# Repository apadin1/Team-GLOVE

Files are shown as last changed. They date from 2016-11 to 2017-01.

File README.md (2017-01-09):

# Team-GLOVE
## EECS 473 Final Project

This project was created as part of a Major Design Experience (MDE) by five senior Computer Engineering students at the University of Michigan. The goal of the project was to create a pair of gloves that could behave as controllers for any PC video game using the standard HID protocol. The gloves collected data from flex sensors in the fingers, capacitive touch sensors in the fingertips, and an IMU mounted on the back of the hand, and transmitted this data wirelessly over bluetooth to a receiver board which translated the data into stardard keyboard and mouse commands. To read more about the results of this project, you can see our [final report](Team%20GLOVE%20Final%20Report.pdf) and [project poster](Team%20GLOVE%20Poster.pptx.pdf) which are included in this repository.

We have decided to make this repository public in the hopes that others could expand upon our work. Our goal is to make video games more fun, intuitive, and immersive, and we hope that you can help.

Sincerely,

Team GLOVE

Nick Bertoldi, Ben Heckathorn, Ryan O'Keefe, Adrian Padin, Tim Schumacher

## Repository Organization
This repository is divided into several sections:
* ConfigApp - Contains code for a Windows app which was used to configure the inputs on the glove. It is mostly written in C#
* Hardware - This folder holdsthe eagle and gerber files for the PCB that was designed to run on the glove
* mbed-dongle-firmware - The code that ran on the reciever board (USB dongle) that did the translation and generated keyboard and mouse commands
* mbed-glove-firmware - The software running on the glove itself to collect sensor data and transmit to the receiver

## Compiling mbed-cli
This project was created using the mbed real-time operating system and libraries. It was specifically designed to run on the NRF51822 processor because of the built-in Bluetooth capabilities. 

To get started with the mbed environment, you can check out their website: www.developer.mbed.org

For instructions on how to setup the mbed-cli, see their documentation page: https://docs.mbed.com/docs/mbed-os-handbook/en/5.1/dev_tools/cli/

You will also need GCC ARM embedded compiler, version 4.9, which can be found here: https://launchpad.net/gcc-arm-embedded/4.9/4.9-2015-q3-update

For Linux users, we recommend installing to /usr/local/ (just `tar -xjvf` the download in that dir)

You will also need git, python, and several python dependencies, as described in the mbed-cli instructions

To setup the enviroment in our repo, go into the mbed-glove-firmware folder and type `mbed-deploy` to update the mbed-os lib

## Contributing
This software is licensed under the Apache 2.0 software license. If you would like to contribute, please submit a pull request and we can review your changes before we apply them. If you would like to use this project as a starting point for other projects, consider forking this repository using the Fork button above. Just be sure to cite this repository in your work!

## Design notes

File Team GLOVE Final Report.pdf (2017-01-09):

# Team GLOVE ‑ Wireless Gaming Gloves

EECS 473
Fall 2016

Team members: Nick Bertoldi, Ben Heckathorn, Ryan O’Keefe, Adrian Padin, Tim Schumacher

## Introduction

Over the course of the last decade, video game makers have sought to create a more immersive experience through high definion graphics, virtual reality, and augmented reality. However, there are currently only two opons for controlling these games: a standard controller, or a keyboard and mouse. The divide between immersive gameplay and a tradional, buᙀon‐based control scheme has created huge demand for a controller soluon that provides a more realisc gaming experience. The focus of our project was to develop a glove‐based controller, which would allow a user’s hand and finger gestures to be translated into control inputs for a
computer game. We were able to accomplish this through the use of touch, moon, and flex sensors to allow for a wide variety of different input methods. These inputs could be used both in exisng games, and as new opons for game developers in the future.

The result of this project was a pair of wireless gloves that handle communicaon via Bluetooth Low Energy (BLE). The gloves could then send input to a Windows computer, and behave like a wireless keyboard and mouse. Each glove contains various sensors used to capture different gestures, which are then translated into PC input. The glove inputs can be adjusted through a configuraon app to allow customizaon of controls for specific games. The final product meets all of the fundamental goals of the original proposal with the excepon of the heart rate sensor, which was removed early in the development cycle due to constraints in engineering me. During the COE Design Expo, several games, including Portal 2 and Fallout 4, were demonstrated successfully via glove control.

## Project Description

The focus of the project was to create a more intuive, immersive, and unique way to interact with exisng computer games. Currently, the main control opons for computer games are either a keyboard and mouse combo, or a USB controller. These input methods rely on the use of several buᙀons, and do not track hand moon or gestures. Therefore, these outdated control methods interrupt the feeling of immersion that computer games aim to provide. There is currently a gap in the market for a controller that feels more natural and does not require the user to hold something and press buᙀons. This means there is currently a demand for a controller that feels more like an extension of our natural movement. Products like the Nintendo Wii and HTC Vive have aᙀempted to fill this gap to some degree, but they sll face technical shortcomings including: inaccurate hand and wrist moon, or reliance on input via buᙀon presses. Ideally, a user should be able to perform acons in the real world, and have them translate directly to on‐screen acons with a high degree of precision. Currently, precision performance capture gloves, designed to track hand posion and gesture, exist, but they are not built for gaming. The integraon of this advanced technology into gaming may be years away, so we chose to develop a glove‐based controller that worked with exisng games in an aᙀempt to bridge the gap between current and future technology.

## High‐Level Descripon

Our group decided to create a pair of gloves that could operate in place of a keyboard and mouse to control exisng computer games. The gloves allow a user to have their hand and finger gestures translated into standard keyboard and mouse inputs. This is accomplished through the use of touch, moon, and flex sensors allowing for a wide variety of gaming inputs for use in both exisng games, and as new opons for future game developers. For example, a user can squeeze their finger and the computer could interpret this as “spacebar”, which could then be interpreted as a jump command. A major benefit of this method is that the gloves can mimic any keyboard or mouse input. Therefore, they can be used with any game, and an easy mapping from hand gestures to in‐game acons can be provided.

It is important to note that the glove is not meant to be a “virtual‐reality” glove. It does not track absolute three‐dimensional hand or finger posion, and it does not provide any hapc or vibraon feedback, which was one of the inial stretch goals. Rather, the focus of this project is to provide a different way to play exisng PC games now, and to build an interface that could easily be integrated into future games. This would allow future games to take advantage of the unique inputs that the gloves provide, and make beᙀer use of the data provided.

## System Layout

The layout of the system is two gloves, one for the le hand and one for the right hand, and a receiver board connected to the computer via USB. Each glove connuously collects data from sensors and then broadcast that sensor data over Bluetooth Low Energy (BLE) to the receiver, which analyzes the data and maps it to standard keyboard and mouse input. This input is sent to the computer using the Human Interface Device (HID) protocol (see Figure 1 below). The sensors on the glove are flex sensors that measure the deflecon of each of the four fingers, capacive touch sensors that funcon like buᙀons when the thumb is pressed to the pad of a finger, and an IMU for moon‐sensing to determine the absolute pitch, roll, and yaw of each hand (layout in Figure 2).

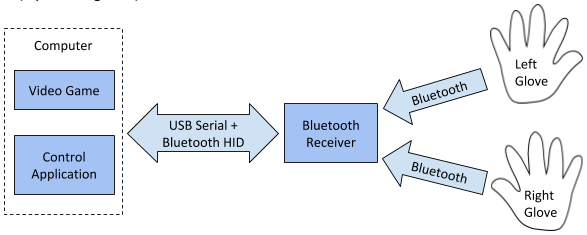
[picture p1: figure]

Figure 1: High‐level diagram of user interacon with the gloves. Gloves collect sensor data from the user and send it via Bluetooth to the receiver.

## Sensors

The gloves use a combinaon of flex sensors, a capacive sensor, and an IMU to capture gestures form the user (Figure 2). The flex sensors are made of a thin, flexible material that has a variable resistance, and measure 2.2” long. The sensor’s resistance changes from 30kΩ when straight to 90kΩ when fully bent. By placing the sensors along the middle knuckle of each finger, the bend of the finger is precisely measured. Along with the flex sensors, the AT42QT1070 capacive touch chip sits on the PCB and connects to the touch sensor pads via wires in the fabric. The touch sensor chip measures the capacitance of the pads, and registers when the value changes. The final on the PCB is the BNO055 IMU. This parcular chip combines a standard IMU with a ARM Cortex M0 to provide euclidian posion informaon to the processor at a rate of 100 Hz.

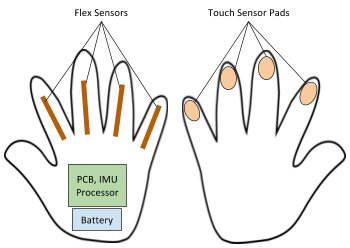
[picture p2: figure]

Figure 2: Layout of sensors in the final glove design. Back of the hand (le) and palm of the hand (right).

## Glove Construcon

The final glove assembly needed to be lightweight, comfortable, self‐contained, and reasonably professional‐looking (see Figure 3). This was important in order to differenate the project from previous glove‐based projects in the class that were fairly haphazard in their construcon, since a poorly‐constructed prototype not only appears unfinished and unprofessional, but can develop funconal issues with loose or poorly connected wires. Our design strategy, therefore, was to start with a preconstructed base glove, aᙀach sensors to it, cover the sensors to protect them, and then only expose the touch pads and status lights. The electronic components would be hidden

The components that make up the final construcon on each base glove include a PCB, four flex sensors, four touch sensor pads, a rechargeable baᙀery, a pair of indicator lights, and wiring to connect it all together. The base gloves are a pair of men’s large, black cycling gloves, with microsuede palms and synthec materials on the fingers. These gloves provide enough space for components to be securely aᙀached, and are easy to sew addional covering onto for the components. The PCB aᙀaches to to the glove at the back of the palm with adhesive velcro to hold it in place while allowing it to be taken out as needed during development. Each flex
sensor is anchored on the first segment of the finger below the knuckle, with the rest of their length inside a spandex sleeve sewn to the finger. Anchoring at the base end relieves stress from the delicate leads, while allowing the sensor to freely bend along with the finger. On the pad of each finger, copper foil is aᙀached to a wire, that then plugs into headers on the PCB. The
copper foil is adhesive and scks to the glove reasonably well, and is then covered around the edges with sewn leather to give it a more finished look and extend the durability of the copper pads. Just above the wrist, the baᙀery sits inside a band of elasc that is sewn into the glove and plugs into the header on the PCB. Finally, a large piece of leather covers the back of the glove and is secured with two sewn in snaps on the side to allow access to the internal components. Access is also required to get to the on/off switch and the micro‐USB header to charge the baᙀery. Built into the cover is the strip of two indicator lights, placed prominently on the gloves to relay status informaon to the user.

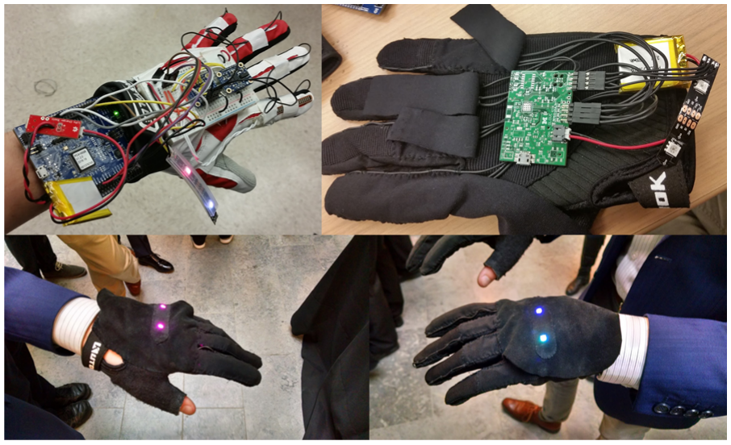
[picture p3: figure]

Figure 3: Prototype glove (top le), parally assembled final glove showing PCB, baᙀery, lights and wiring (top right), fully assembled and working gloves (boᙀom).

## PCB Design

A printed circuit board (PCB) was used to secure and arrange the processor, sensor chips, and Bluetooth antenna. This board allowed the final gloves to have a more rigid and compact structure than our prototype. The pcb had no explicit size requirement, aside from the need to fit on the back of an average adult hand; however, the final result is comparavely dense with an area close to 3 in ²

. Both gloves share an idencal PCB (shown in Figure 4).

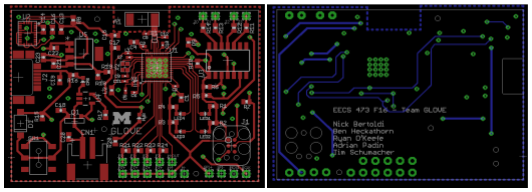
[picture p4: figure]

Figure 4: Eagle files screenshots of the PCB design, top (le) and boᙀom (right).

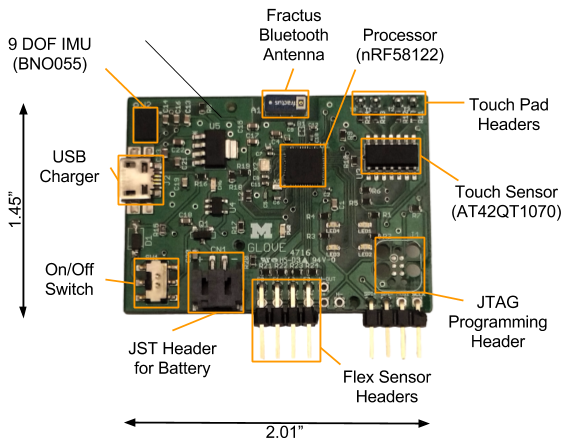
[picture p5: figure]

Figure 5: Layout of the major components on the PCB, including the processor and sensors

## Configuraon App

The mapping of sensor data to keyboard and mouse input can be adjusted through the Glove Configuraon App (Figure 6). The Windows applicaon allows the user to change the input associated with each sensor. Any of the fourteen inputs on each hand can be mapped to any standard keyboard key, or mouse input, which includes of cursor movement and buᙀon clicks. This allows the user to play a variety of games with the gloves, as well as le靀ng the user customize their gaming experience based on which acons seem more natural.

Due to the adjustable inputs, a user is not required to use both hands at mes, or be restrained to using certain fingers for specific acons. Currently, this is a major limitaon in games that use a keyboard and mouse because mice are not usually designed to be le‐handed, and keyboards can have fixed se靀ngs.

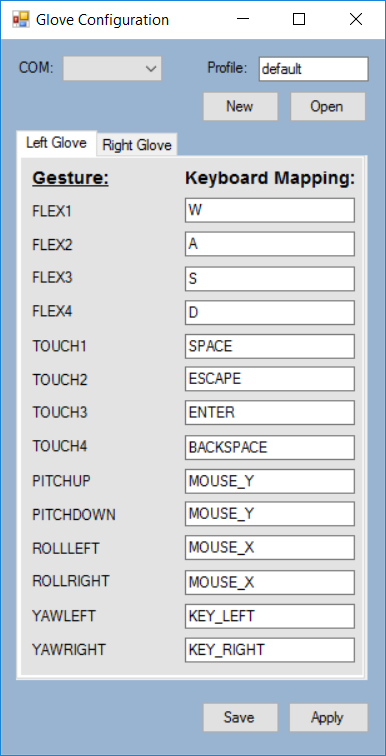
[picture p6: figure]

Figure 6: The configuraon app

## Schedule, Milestones, and Budget

Due to soware and hardware delays, the project was consistently behind schedule by roughly two weeks when compared to the proposed schedule. The details of a few important me and budget setbacks are detailed later in this report. To offset the hardware producon issues, we decided to focus on soware earlier on to minimize tesng once we received our PCBs.

The original milestone deliverables consisted of the following items:

Milestone 1
- Flex and touch sensors working, reading data properly
- Bluetooth communication scheme implemented and completed
- Receiver able to get commands from computer over USB
- Receiver able to send data through a HID profile
- Able to collect IMU data and interpret it somehow
- Starng work on desktop configuraon app

Milestone 2
- PCBs designed and ordered
- Prototype completed, usable with at least one game
- IMU, flex, touch, heart rate sensors all reading data correctly
- Desktop app almost finished, usable with prototype
- Several HID profiles implemented, configurable through desktop app

Overall, the order in which these tasks were completed did not change. Nearly every task started about a week later than planned, and finished about two weeks later than previously ancipated. The original schedule had allowed for two weeks of tesng and playing with the final product, so, as a result, that tesng me had to be reduced to three days. However, all of the original milestone projecons and features were incorporated into the final product.

The budget stayed similar to the proposed budget. Certain features had to be cut out early on, such as the hapc feedback, which was one of the original stretch goals. As a result, the buzzer motors were not purchased and fewer flex sensors were bought. There were also a series of unforeseen expenses. The biggest change to the budget was due to the delay in the original PCB order. The boards were designed and ordered the weekend before the given deadline on November 8th, but due to shipping issues they did not arrive unl November 30th, which was a full week aer the vendor’s adversed worst case delivery me. Once it was clear that the shipment would be delayed, the group made the decision to do a second order from a more reputable site, but it sll cost extra for expedited shipping to meet the deadline. Also, several mistakes were made when soldering the boards that meant that various other components also needed to be reordered. However, the budget had a conngency for this parcular problem and it did not cause any major issues.

## Lessons Learned

There were many mistakes that were made and many lessons that were learned the hard way in this project. The first issues arose with our original PCB design. Since no one in the group had the knowledge nor inclinaon to make our own component footprints, we at first limited ourselves to only using components for which we could find an exisng footprint to use in Eagle, an easy to use PCB design program. We quickly realized that this was not sufficient since some of our crical components such as the moon and touch sensors did not already have footprints. We also realized aer we ordered our boards that we should have added several useful debugging features such as a so reset buᙀon, and USB data lines to read debugging informaon off of our processor. In addion, we should not have ordered our boards from a website which were not experienced with, as it caused delays of nearly a week and a half and ended up being lower quality than the boards we ordered later.

One very difficult issue was the use of HID for our keyboard and mouse input. At first we thought this would be easy because it seemed to be a cross‐plaᔀorm soluon with good documentaon. However, there ended up being very few hardware devices which supported true USB/HID, and integrang those devices seemed like an immense challenge. One of our group members discovered that we could implement HID over Bluetooth Low Energy and it seemed to work well at first. However, stability issues and connecon drops ended up plaguing the project throughout its development. For example, if the device tried to send commands at too fast of a rate, the Bluetooth stack would get overloaded aer a few minutes of playing a game and stop sending commands. Another major issue we encountered was when integrang a second glove aer ge靀ng the first glove working; the two gloves would oen overwrite each other's commands and inaccurate data would be sent. These issues were compounded by the use of the ARM mbed toolchain which was used to write our soware, which turned out to have bugs and did not support all of the features that it adversed. In the long run, it probably would have been beᙀer to use a board such as the PJRC Teensy, which implements USB funconality rather than use HID over BLE.

Despite these issues and several more, our team learned a lot about embedded systems design. A big part of this learning process was having to start our project from scratch, picking a processor and designing a PCB based on our requirements. We learned about how Bluetooth Low Energy communicaon works and how to balance tasks which require long amounts of me to run, such as scanning and sending data over Bluetooth. We also learned that prototyping is crical to determine exactly what is feasible and how best to implement ideas in order to catch mistakes early on.

## Contributions

Nick Bertoldi (20%) ‐ Nick contributed to the PCB design and tesng. He performed research into the communicaon scheme and wrote code and tests around HID over GATT communicaon and GAP adversements. He also designed and implemented the backend to the configuraon applicaon and designed serial communicaon code to interface with the receiver board.

Ben Heckathorn (20%) ‐ Ben contributed primarily to soware design and integraon. He also helped develop the high‐level communicaon scheme between the gloves, receiver, and CPU. He helped write the soware that translates glove data to HID input, and developed it to be completely configurable so that any sensor can map to any HID input. Ben also wrote porons of the receiver code by integrang various pieces of soware into the final version. In addion, Ben also designed the interface for the glove configuraon applicaon.

Ryan O’Keefe (20%) ‐ Ryan contributed to the PCB design layout. He also soldered together the PCBs when they came in. He fixed the touch sensor breakout board that we acquired for prototyping. He performed performance checking and debugging of the PCBs and fixed any soldering issues associated. Ryan also helped write the soware that translates the data coming from the sensors into a specific kind of input ‐ HID. He helped make the soware configurable so that any arbitrary sensor could be mapped to any arbitrary HID input.

Adrian Padin (20%) ‐ Adrian contributed primarily to the Bluetooth Low Energy and HID soware. He developed drivers for using BLE to send keyboard and mouse data and wrote the porons of the receiver code that scan for glove data and send HID data to the computer. Adrian also helped write a good poron of the Milestone and Final reports and created figures for the final report showing the high‐level diagram and glove layout.

Tim Schumacher (20%) ‐ Tim started by prototyping the flex, touch, and orientaon sensors by breadboarding them in the lab and wring the first drivers to collect sensor data. He connued to refine the sensor drivers and also developed the rest of the glove firmware that collects data from the sensors, sends BLE adversements with the sensor data, and controls the indicator lights on the glove. In addion to the glove firmware, he designed and built the prototype and final gloves, with much of the sewing assembly done in conjuncon with his mom, Marci Schumacher.

## Cost to Manufacture

We esmate that a reasonable quanty to manufacture this product as a consumer electronic device is 10,000 units. This number is based on the assumpon that this is an experimental device, but one that has a reasonably large pool of potenal buyers. In this instance, the potenal buyers are anyone who does PC gaming, and is reduced by the number of people who are willing to try the gloves and who can afford them.

The cost per board at this quanty would be approximately $22.50, which includes fabricang the boards, purchasing components, and assembling the boards. This does not include the cost of purchasing the materials for the glove and sewing them, but it otherwise gives a preᙀy reasonable expectaon of manufacturing costs, though perhaps a bit high if quanty discounts were considered.

## Final Parts List and Budget

The following two pages contain a spreadsheet of the complete part list of every component used to build this project and the total list of expenses. The part list covers all of the parts needed to make four boards, one set of complete gloves, and an extra glove as backup. The parts list is divided into the following secons:

Board components are all of the passive and acve components that had to be soldered to the board. This includes all of the passive components, such as resistors, capacitors, LEDs, oscillators, and transistors, and the acve components such as the touch sensors, IMU, and processor.

System components are parts that are needed to make any number of gloves, such as the leather and PCBs. Whereas the board components can be scaled down by a factor of four to make a single glove, these system parts are needed to make any number of boards.

Extra parts are parts that were used by the team in the development of this project but are not necessary to construct the final product. This includes items such as development kits, resistor kits, and spare components. Any parts which were used to make the prototype glove such as sensor breakout boards and programming materials are also included.

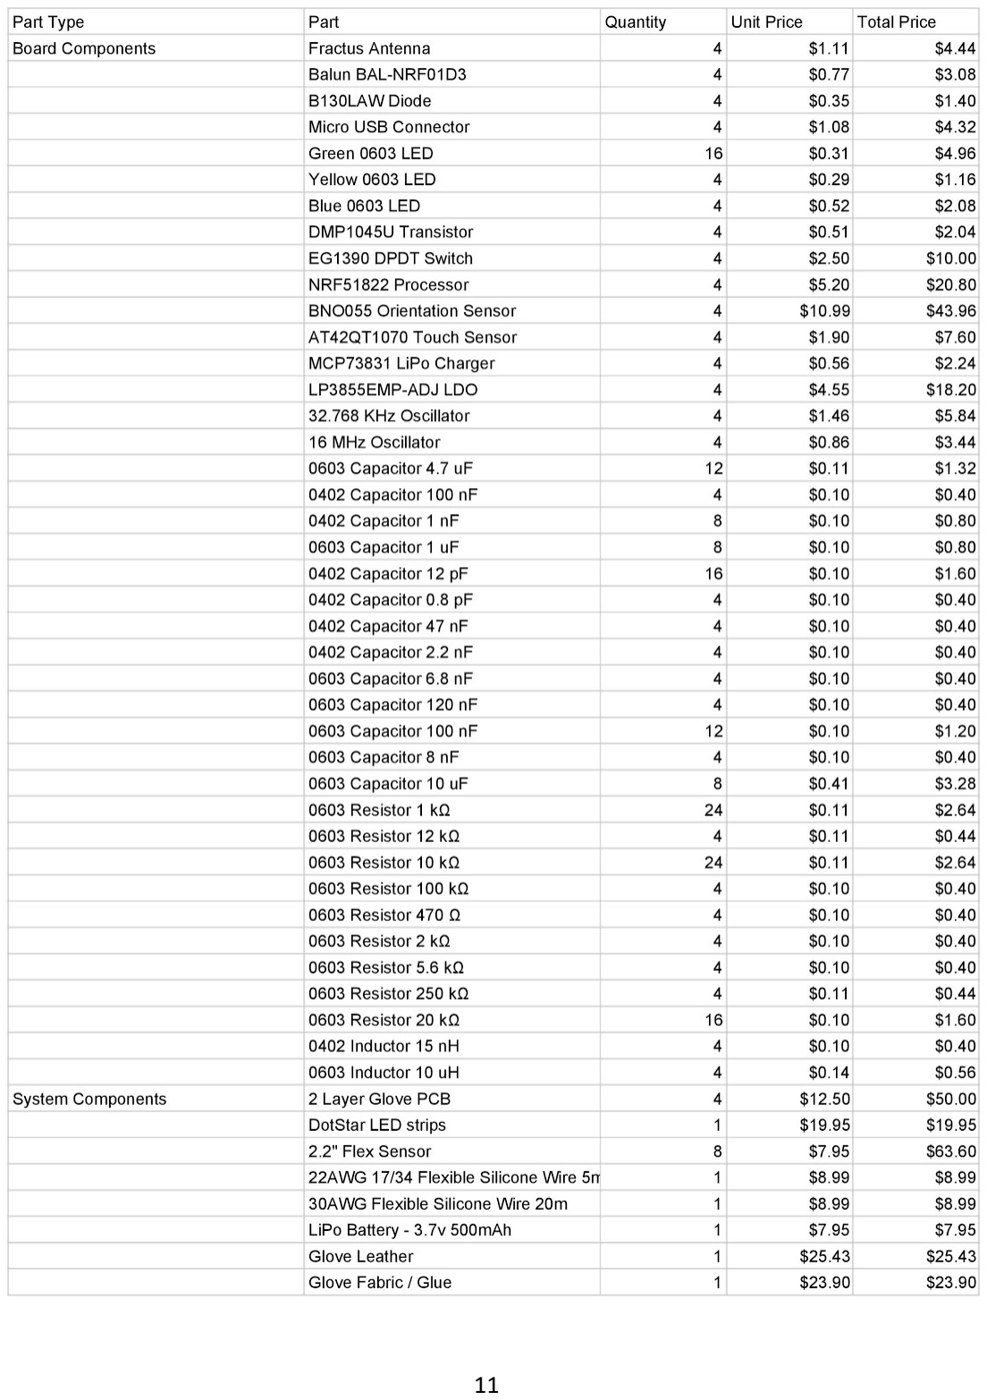
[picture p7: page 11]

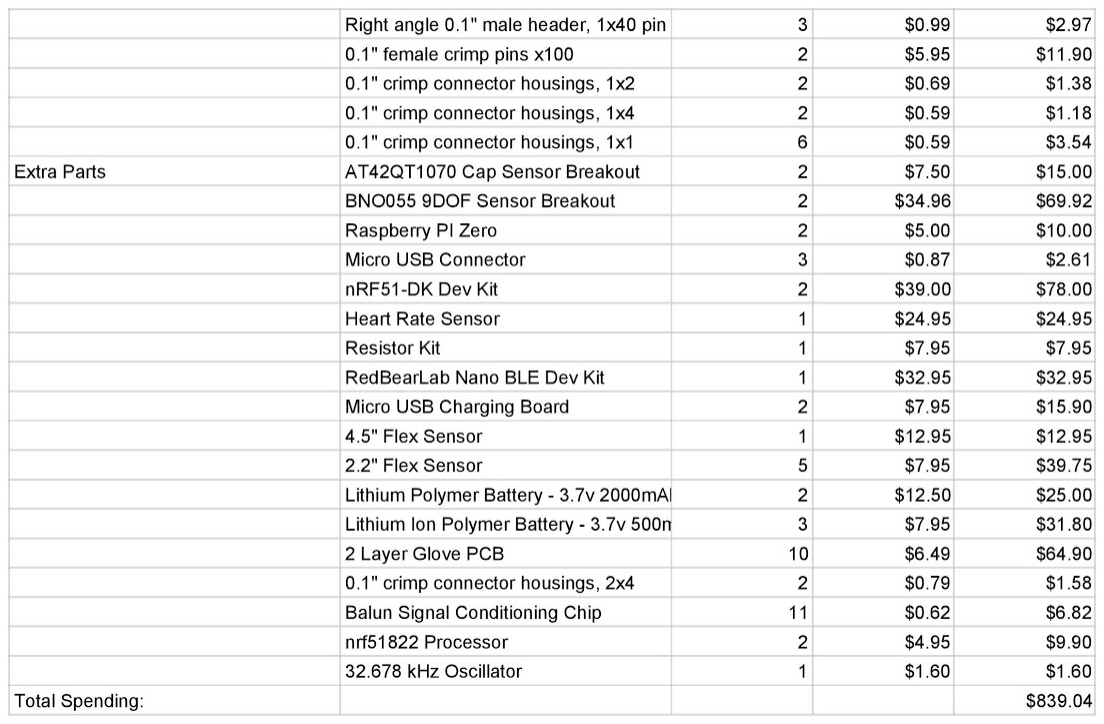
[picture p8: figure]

Note that the list does not cover shipping costs, which put the final expense value much closer to the maximum provided budget of $1,000. The final total cost was $999.91.

## References and Citations

All code was developed using the ARM mbed toolchain and compiled using the ARM‐GCC compiler. More informaon about ARM mbed can be found at there website here: hᙀps://developer.mbed.org/ .

Several hardware and soware design choices were based on similar designs from Lab 11. Credit goes to the Lab 11 crew for helping with these designs, especially the charging circuit and the Bluetooth antenna setup.

Special thanks goes to Branden Ghena, one of the Lab 11 staff who helped us a lot with both the final PCB design review, and bluetooth adversement debugging and opmizaon.

The 473 GSI Seth Goldstein helped us design parts of our PCB as well. He provided sample code from his EECS 473 project that helped us write the code to scan for bluetooth adversements and receive data from the computer over USB.

For more informaon about our project and to see our code for yourself, visit our Github repository: hᙀps://github.com/apadin1/Team‐GLOVE (https://github.com/apadin1/Team-GLOVE) .

## Appendix A: Completed PCB

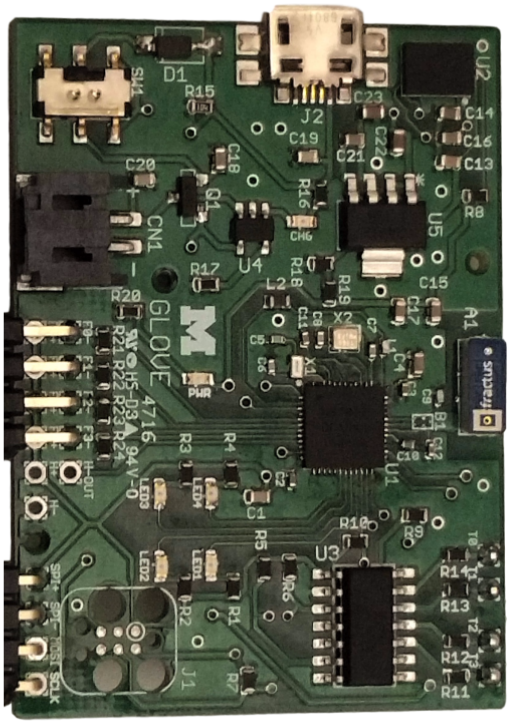
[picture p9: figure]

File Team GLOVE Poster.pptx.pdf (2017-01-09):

## Overview

The focus of the project is to create a more intuitive, immersive, and interesting way to interact with existing computer games. Traditional games are controlled using a keyboard and mouse, but gamers are eager for new ways to interact with the virtual world. Our solution was to create a glove-based controller that translated the user’s gestures into standard keyboard and mouse commands.

## Glove Sensors

A variety of sensors are incorporated into the gloves to give users different ways to interact with their games. Resistive flex sensors
(1) are placed along the knuckles detect when the user bends their fingers. A capacitive touch sensor (2) detects when the user touches their exposed thumb to the metal pads located on their fingertips. Lastly, an inertial measurement unit (3) detects when the user rotates their hand around an axis.

## PCB Design

Each glove has an identical printed circuit board (PCB) which connects the processor to its sensors. The sensors communicate to the processor over I²C and SPI protocols. The gloves can last up to 14 hours on a single charge. Status LEDs on the back of the hand communicate with the processor over SPI, and can indicate various programmable events. Once soldered, the circuit board is sewn into the glove to keep it secure.

## Using the Gloves

The setup consists of two gloves and a receiver board. Each glove continuously collects data from each finger’s flex sensor, capacitive touch sensor, and the IMU for motion-sensing. The gloves then broadcast the sensor data over Bluetooth to the receiver board, which is plugged into the USB port of the computer. The receiver analyzes the data and maps it to standard keyboard and mouse input to send to the computer.

## The HID Protocol

The Human Interface Device protocol (HID) is a standardized communication schemel used to send data to the computer from common input devices. This is what allows you to buy any keyboard off the shelf, plug it into your computer, and have it work instantly without need to install a new driver.

We chose HID for this project
because it allows the glove to
connect to any computer disguised as a keyboard and mouse, thus making it easy to use with existing computer games. Any game
that can be controlled with
a keyboard and/or mouse can be controlled with the gloves.

## Configuration App

## Prototyping

In order to test the software as it was being developed, a prototype glove needed to be created.The glove (5) incorporated each type of sensor used in the final glove, as well as a development kit to process the data and a mess of wires.

## Final Construction

The final gloves are built on top of a bike glove base layer. The thumb is exposed to allow for touch sensor input. The flex and capacitive sensors are attached to the fingers, and the PCB and battery are attached to the back of the hand. Suede covers the internals of the glove to create a functional and complete wearable device as demonstrated below (6).

# Wireless Interactive Glove-Based Controller for Computer Games

Nick Bertoldi, Ben Heckathorn, Ryan O’ Keefe, Adrian Padin, Tim Schumacher Fall 2016 – EECS 473: Advanced Embedded Systems

Special thanks to Professor Mark Brehob, Matt Smith, Branden Ghena, and Seth Goldstein for their support and assistance and thanks to Marci Schumacher for assistance in glove construction. Thanks as well to Boeing for providing funding for this project and for supporting EECS 473 and the College of Engineering at the University of Michigan.

Bluetooth

Bluetooth

Figure 5. Prototype glove featuring the nRF51-DK, DotStar LEDs, touch sensors, flex sensors, and IMU

Figure 1. Flex Sensor | Figure 2. Capacitive Touch Sensor
Figure 3. IMU

Figure 4. PCB Schematic (top) compared to the constructed PCB (bottom)

The Configuration App allows the user to change the command that each sensor controls. For instance, in the default settings shown right (8), bending the index finger of the left glove sends a “W” command to the computer, and rotating the left wrist moves the mouse cursor left and right. The ability to change the configuration allows the user to map
the inputs to fit their preferences. Figure 6. Final glove design with fabric pulled back to see the components and wiring

Figure 8. Interface for the configuration app

Figure 7. Communication scheme for Gloves

3.9mm

8.65mm
55.88mm

5.20mm

3.80mm

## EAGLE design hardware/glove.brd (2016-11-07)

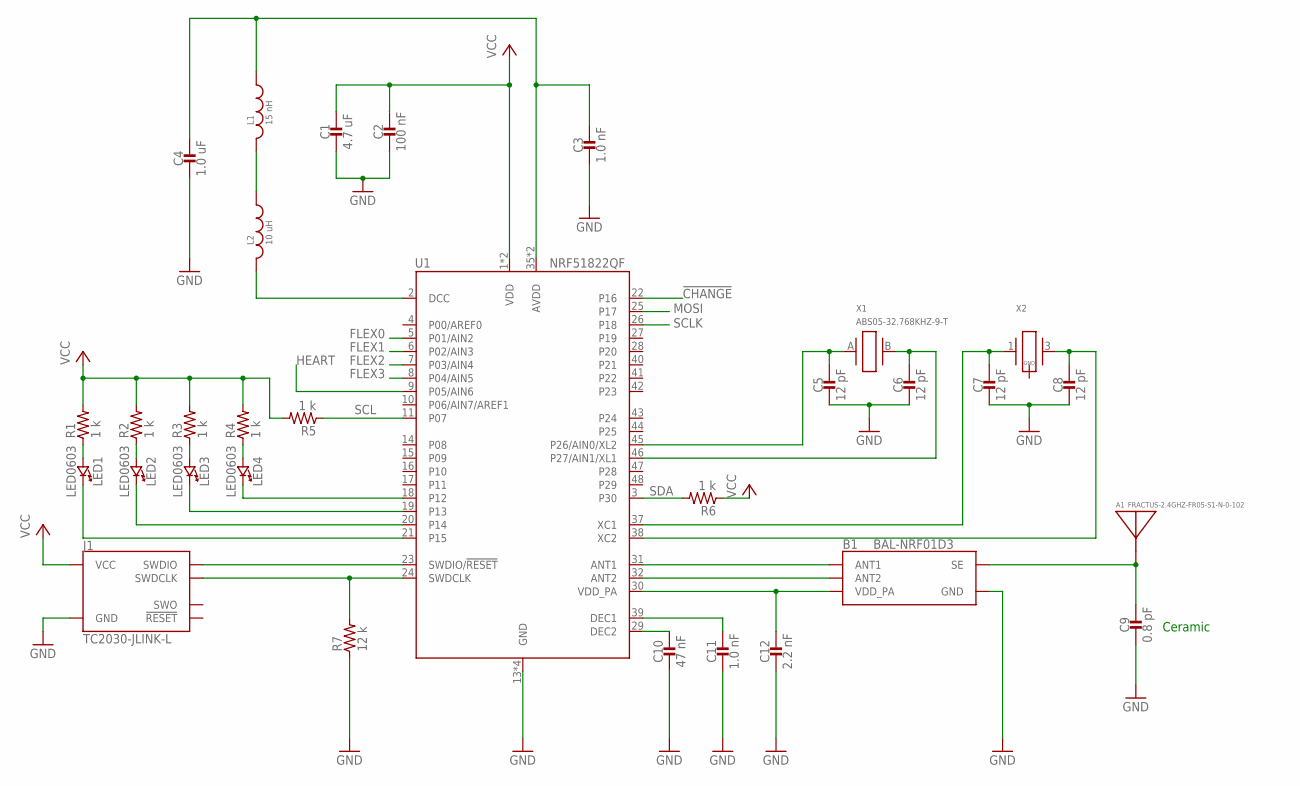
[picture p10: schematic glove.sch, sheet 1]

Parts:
A1: FRACTUS-2.4GHZ-FR05-S1-N-0-102; FRACTUS-ANTENNA-FR05-S1-N-0-102
B1: BAL-NRF01D3
C1: 4.7 uF; 0603_CAP
C2: 100 nF; 0402_CAP
C3, C11: 1.0 nF; 0402_CAP
C4: 1.0 uF; 0603_CAP
C5, C6, C7, C8: 12 pF; 0402_CAP
C9: 0.8 pF; 0402_CAP
C10: 47 nF; 0402_CAP
C12: 2.2 nF; 0402_CAP
J1: TC2030-JLINK-L; TC2030-IDC
L1: 15 nH; 0402_CAP
L2: 10 uH; 0603_CAP
LED1, LED2, LED3, LED4: LED0603; LED-0603
R1, R2, R3, R4, R5, R6: 1 k; 0603-RES
R7: 12 k; 0603-RES
U1: NRF51822QF; QFN-48-6MM
X1: ABS05-32.768KHZ-9-T; ABS05
X2: TXC-8Y

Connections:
!CHANGE: U1.22 (P16); also elsewhere on the board
FLEX0: U1.5 (P01/AIN2); also elsewhere on the board
FLEX1: U1.6 (P02/AIN3); also elsewhere on the board
FLEX2: U1.7 (P03/AIN4); also elsewhere on the board
FLEX3: U1.8 (P04/AIN5); also elsewhere on the board
GND: B1.GND, C1.2, C2.2, C3.2, C4.2, C5.2, C6.2, C7.2, C8.2, C9.2, C10.2, C11.2, C12.2, J1.5 (GND), R7.1, U1.13 (GND), U1.33 (GND), U1.34 (GND), U1.GND; also elsewhere on the board
HEART: U1.9 (P05/AIN6); also elsewhere on the board
MOSI: U1.25 (P17); also elsewhere on the board
unnamed: LED2.C (CATHODE), U1.20 (P14)
unnamed: LED2.A (ANODE), R2.1
unnamed: LED1.C (CATHODE), U1.21 (P15)
unnamed: LED1.A (ANODE), R1.1
unnamed: LED4.C (CATHODE), U1.18 (P12)
unnamed: LED4.A (ANODE), R4.1
unnamed: L2.2, U1.2 (DCC)
unnamed: L1.2, L2.1
unnamed: C3.1, C4.1, L1.1, U1.35 (AVDD), U1.36 (AVDD)
unnamed: J1.2 (SWDIO), U1.23 (SWDIO/!RESET)
unnamed: C8.1, U1.38 (XC2), X2.3 (2)
unnamed: B1.ANT1, U1.31 (ANT1)
unnamed: B1.ANT2, U1.32 (ANT2)
unnamed: B1.VCC (VDD_PA), C12.1, U1.30 (VDD_PA)
unnamed: A1.1, B1.SE, C9.1
unnamed: C10.1, U1.29 (DEC2)
unnamed: C11.1, U1.39 (DEC1)
unnamed: C5.1, U1.45 (P26/AIN0/XL2), X1.A (1)
unnamed: C6.1, U1.46 (P27/AIN1/XL1), X1.B (2)
unnamed: C7.1, U1.37 (XC1), X2.1
unnamed: J1.4 (SWDCLK), R7.2, U1.24 (SWDCLK)
unnamed: LED3.A (ANODE), R3.1
unnamed: LED3.C (CATHODE), U1.19 (P13)
SCL: R5.1, U1.11 (P07); also elsewhere on the board
SCLK: U1.26 (P18); also elsewhere on the board
SDA: R6.2, U1.3 (P30); also elsewhere on the board
VCC: C1.1, C2.1, J1.1 (VCC), R1.2, R2.2, R3.2, R4.2, R5.2, R6.1, U1.1 (VDD), U1.12 (VDD); also elsewhere on the board

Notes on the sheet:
Ceramic

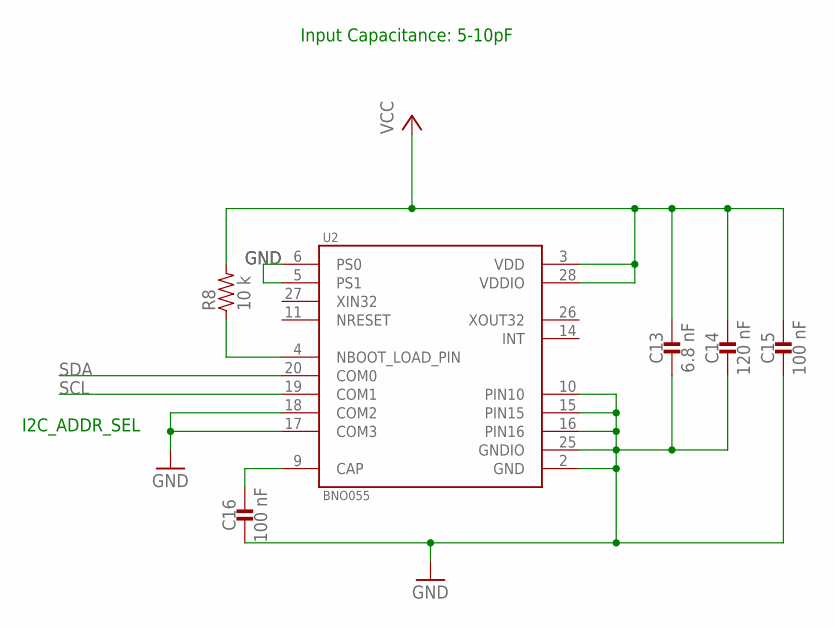
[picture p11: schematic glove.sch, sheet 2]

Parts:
C13: 6.8 nF; 0603_CAP
C14: 120 nF; 0603_CAP
C15, C16: 100 nF; 0603_CAP
R8: 10 k; 0603-RES
U2: BNO055; LGA28R50P4X10_380X520X100

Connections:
GND: C13.2, C14.2, C15.2, C16.2, U2.2 (GND), U2.5 (PS1), U2.6 (PS0), U2.10 (PIN10), U2.15 (PIN15), U2.16 (PIN16), U2.17 (COM3), U2.18 (COM2), U2.25 (GNDIO); also elsewhere on the board
unnamed: C16.1, U2.9 (CAP)
unnamed: R8.1, U2.4 (NBOOT_LOAD_PIN)
SCL: U2.19 (COM1); also elsewhere on the board
SDA: U2.20 (COM0); also elsewhere on the board
VCC: C13.1, C14.1, C15.1, R8.2, U2.3 (VDD), U2.28 (VDDIO); also elsewhere on the board

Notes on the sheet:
I2C_ADDR_SEL
Input Capacitance: 5-10pF

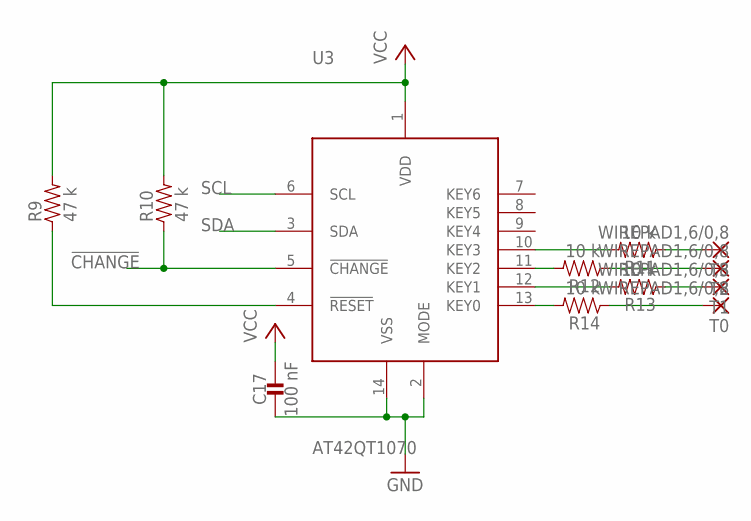
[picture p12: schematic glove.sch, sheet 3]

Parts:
C17: 100 nF; 0603_CAP
R9, R10: 47 k; 0603-RES
R11, R12, R13, R14: 10 k; 0603-RES
T0, T1, T2, T3: WIREPAD1,6/0,8; 1,6/0,8
U3: AT42QT1070; QT1070

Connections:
!CHANGE: R10.1, U3.5 (!CHANGE); also elsewhere on the board
GND: C17.2, U3.2 (MODE), U3.14 (VSS); also elsewhere on the board
unnamed: R11.2, U3.10 (KEY3)
unnamed: R11.1, T3.1
unnamed: R12.2, U3.11 (KEY2)
unnamed: R12.1, T2.1
unnamed: R13.2, U3.12 (KEY1)
unnamed: R13.1, T1.1
unnamed: R14.2, U3.13 (KEY0)
unnamed: R14.1, T0.1
unnamed: R9.1, U3.4 (!RESET)
SCL: U3.6 (SCL); also elsewhere on the board
SDA: U3.3 (SDA); also elsewhere on the board
VCC: C17.1, R9.2, R10.2, U3.1 (VDD); also elsewhere on the board

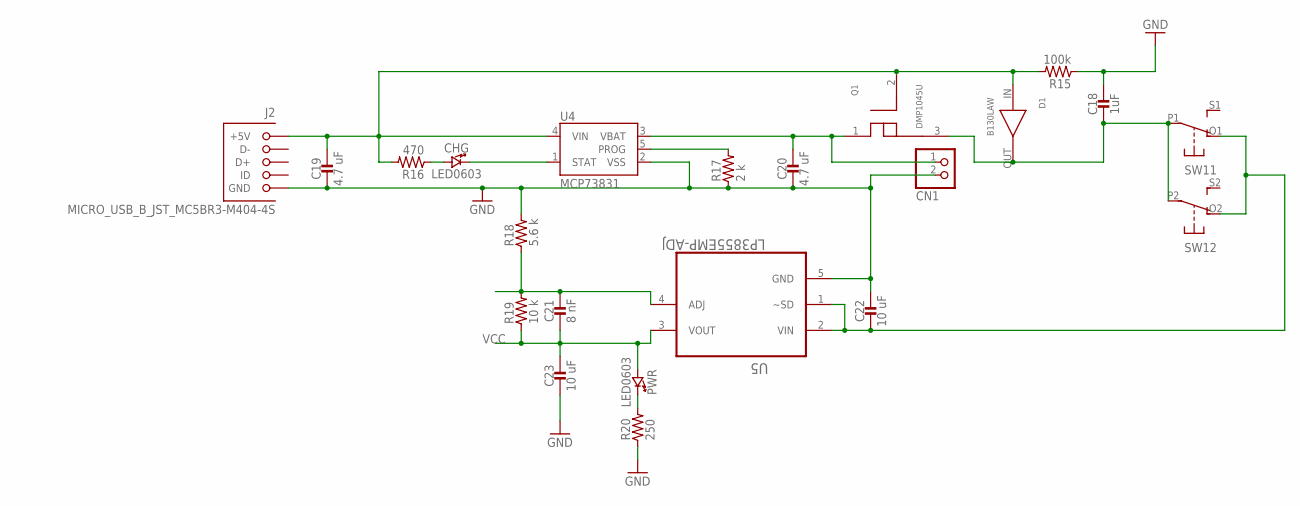
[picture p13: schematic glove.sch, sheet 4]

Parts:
C18: 1uF; 0603_CAP
C19, C20: 4.7 uF; 0603_CAP
C21: 8 nF; 0603_CAP
C22, C23: 10 uF; 0603_CAP
CHG: LED0603; LED-0603
CN1: JST_2PIN-SMT-RA; JST-PH-2-SMT-RA
D1: B130LAW; 2PIN
J2: MICRO_USB_B_JST_MC5BR3-M404-4S; USB_MICRO_B-JST-MC5BR3-M404-4S-TB
PWR: LED0603; LED-0603
Q1: DMP1045U; 3PIN
R15: 100k; 0603-RES
R16: 470; 0603-RES
R17: 2 k; 0603-RES
R18: 5.6 k; 0603-RES
R19: 10 k; 0603-RES
R20: 250; 0603-RES
SW1: DPDT-EG1390; EG1390
U4: MCP73831; SOT23-5
U5: LP3855EMP-ADJ; SOT150P696X180-5N

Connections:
GND: C18.1, C19.2, C20.2, C22.1, C23.2, CN1.2 (1), J2.5 (GND), R15.1, R17.1, R18.2, R20.1, U4.2 (VSS), U5.5 (GND); also elsewhere on the board
unnamed: C18.2, D1.OUT, Q1.3 (SOURCE), SW1.P1, SW1.P2
unnamed: CHG.A (ANODE), R16.1
unnamed: CHG.C (CATHODE), U4.1 (STAT)
unnamed: R17.2, U4.5 (PROG)
unnamed: C21.1, R18.1, R19.2, U5.4 (ADJ)
unnamed: PWR.C (CATHODE), R20.2
unnamed: C19.1, D1.IN, J2.1 (+5V), Q1.2 (GATE), R15.2, R16.2, U4.4 (VIN)
unnamed: C20.1, CN1.1 (2), Q1.1 (DRAIN), U4.3 (VBAT)
unnamed: C22.2, SW1.O1 (O), SW1.O2 (O), U5.1 (~SD), U5.2 (VIN)
VCC: C21.2, C23.1, PWR.A (ANODE), R19.1, U5.3 (VOUT); also elsewhere on the board

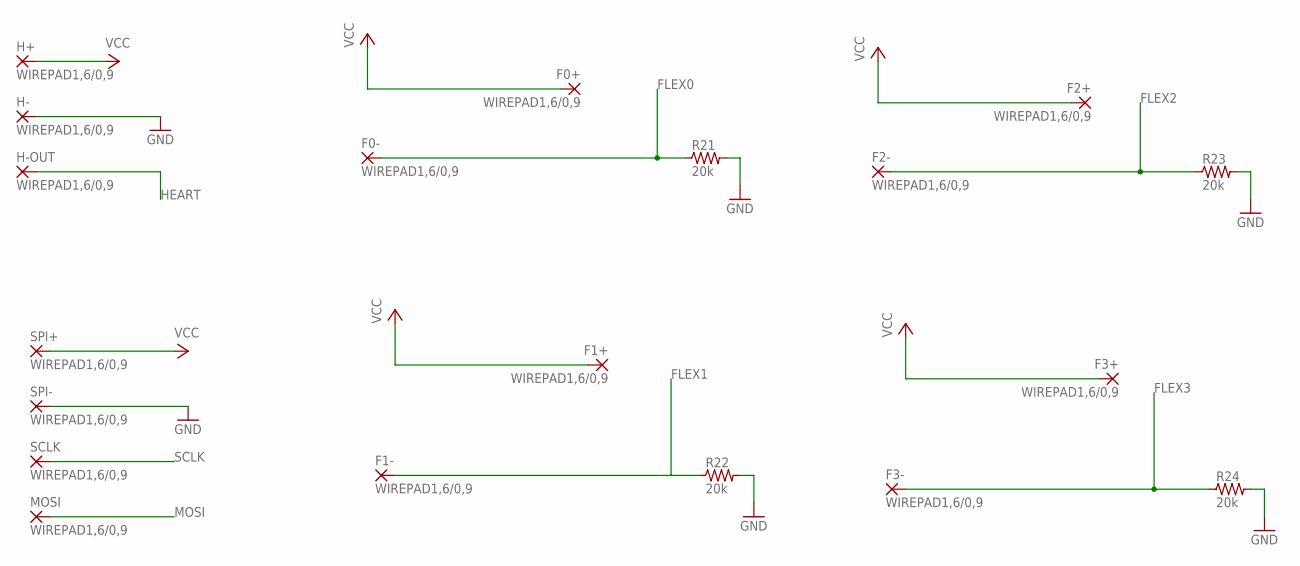
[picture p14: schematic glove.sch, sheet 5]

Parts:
F0+, F0-, F1+, F1-, F2+, F2-, F3+, F3-: WIREPAD1,6/0,9; 1,6/0,9
H+: WIREPAD1,6/0,9; 1,6/0,9
H-: WIREPAD1,6/0,9; 1,6/0,9
H-OUT: WIREPAD1,6/0,9; 1,6/0,9
MOSI: WIREPAD1,6/0,9; 1,6/0,9
R21, R22, R23, R24: 20k; 0603-RES
SCLK: WIREPAD1,6/0,9; 1,6/0,9
SPI+: WIREPAD1,6/0,9; 1,6/0,9
SPI-: WIREPAD1,6/0,9; 1,6/0,9

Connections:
FLEX0: F0-.1, R21.1; also elsewhere on the board
FLEX1: F1-.1, R22.1; also elsewhere on the board
FLEX2: F2-.1, R23.1; also elsewhere on the board
FLEX3: F3-.1, R24.1; also elsewhere on the board
GND: H-.1, R21.2, R22.2, R23.2, R24.2, SPI-.1; also elsewhere on the board
HEART: H-OUT.1; also elsewhere on the board
MOSI: MOSI.1; also elsewhere on the board
SCLK: SCLK.1; also elsewhere on the board
VCC: F0+.1, F1+.1, F2+.1, F3+.1, H+.1, SPI+.1; also elsewhere on the board

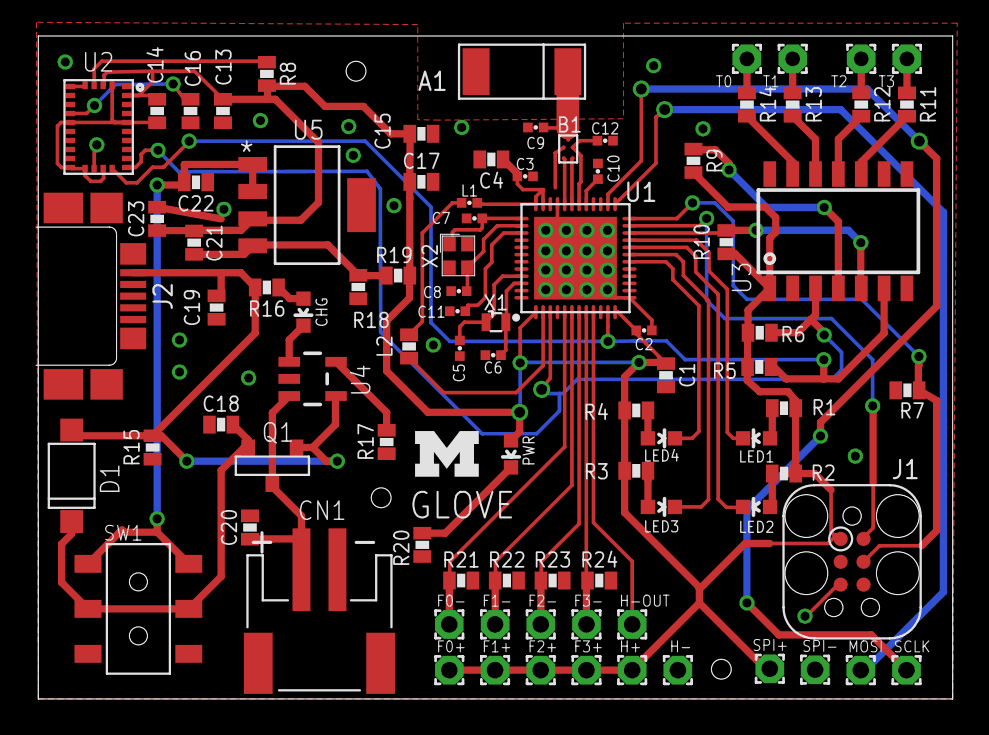
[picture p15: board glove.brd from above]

Board: 2 copper layers, 50.8 x 36.8 mm, 90 parts (0 on the bottom side), 55 nets.

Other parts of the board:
U$1: UMICH_SOLID_100MIL

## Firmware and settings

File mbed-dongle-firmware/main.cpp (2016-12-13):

/*
 * Copyright (c) 2016 by Nick Bertoldi, Ben Heckathorn, Ryan O'Keefe,
 *                       Adrian Padin, Timothy Schumacher
 *
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
 * THE SOFTWARE IS PROVIDED "AS IS", WITHOUT WARRANTY OF ANY KIND, EXPRESS
 * OR IMPLIED, INCLUDING BUT NOT LIMITED TO THE WARRANTIES OF MERCHANTABILITY,
 * FITNESS FOR A PARTICULAR PURPOSE AND NONINFRINGEMENT. IN NO EVENT SHALL
 * THE AUTHORS OR COPYRIGHT HOLDERS BE LIABLE FOR ANY CLAIM, DAMAGES OR OTHER
 * LIABILITY, WHETHER IN AN ACTION OF CONTRACT, TORT OR OTHERWISE, ARISING FROM,
 * OUT OF OR IN CONNECTION WITH THE SOFTWARE OR THE USE OR OTHER DEALINGS
 * IN THE SOFTWARE.
 */

#include "gpio.h"
#include "string.h"

#include "drivers/scanner.h"
#include "drivers/serial_com.h"
#include "drivers/translator.h"
#include "drivers/translate_task.h"
#include "drivers/glove_sensors.h"

BLE& ble = BLE::Instance(BLE::DEFAULT_INSTANCE);

extern int left_count;
extern int right_count;
void printPacketCounts() {
    printf("left: %d\r\nright: %d\r\n", left_count, right_count);
}

// Wait for events in a constant loop to make sure the BLE stack
// gets serviced in a reasonable time
void bleWaitForEventLoop() {
    while (true) {
        led3 = 1;
        ble.waitForEvent();
        led3 = 0;
    }
}
#define IS_LEFT true
#define IS_RIGHT false

// Driver for dongle
void launch() {

    // Turn off LEDs
    led1 = 1; led2 = 1; led3 = 1; led4 = 1;

    // Glove data structs
    static glove_sensors_raw_t left_glove_data;
    static glove_sensors_raw_t right_glove_data;
    static glove_sensors_compressed_t left_compressed;
    static glove_sensors_compressed_t right_compressed;

    // Initialize ble
    ble.init();

    // Initialize KeyboardMouse object
    KeyboardMouse HIDinput(ble);

    flexToHID flex_sensors_L[FLEX_COUNT];
    touchToHID touch_sensors_L[TOUCH_COUNT];
    imuToHID imu_axis_L[IMU_COUNT];
    flexToHID flex_sensors_R[FLEX_COUNT];
    touchToHID touch_sensors_R[TOUCH_COUNT];
    imuToHID imu_axis_R[IMU_COUNT];

    // Initialize translators
    Translator leftTranslator(left_glove_data, HIDinput, IS_LEFT, flex_sensors_L, touch_sensors_L, imu_axis_L);
    Translator rightTranslator(right_glove_data, HIDinput, IS_RIGHT, flex_sensors_R, touch_sensors_R, imu_axis_R);
    TranslateTask combinedTask(leftTranslator, rightTranslator, HIDinput);

    // Init scanner
    crcInit();
    //Scanner scanner(ble, left_glove_data, right_glove_data);
    Scanner scanner(ble, &left_compressed, &right_compressed, left_glove_data, right_glove_data);

    // Initialize serial interrupts for configuration
    //serialInit(&leftTranslator, &rightTranslator, &scanner);

    // Setup the waitForEvent loop in a different thread
    Thread bleWaitForEvent(bleWaitForEventLoop);

    // Infinite loop with two states
    // Either the keyboard is connected or unconnected
    while (true) {
#if 0
        scanner.startScan(100, 25);
        for (;;) {
            led1 != led1;
            extractGloveSensors(left_glove_data, &left_compressed);
            extractGloveSensors(right_glove_data, &right_compressed);
            printf("%d, %d, | %f %f || %d, %d | %f, %f\r\n",
                    left_glove_data.flex_sensors[0], left_glove_data.flex_sensors[3],
                    left_glove_data.imu.orient_pitch, left_glove_data.imu.orient_roll,
                    right_glove_data.flex_sensors[0], right_glove_data.flex_sensors[3],
                    right_glove_data.imu.orient_pitch, right_glove_data.imu.orient_roll);
            Thread::wait(500);
        }
#endif

        // UNCONNECTED STATE
        while (!HIDinput.isConnected()) {
            led4 = !led4;
            Thread::wait(10);
        }

        // Wait for connection to take place
        Thread::wait(3000);

        // Start scanning and translating
        combinedTask.startUpdateTask(25); // 50 is stable, 25 is playable...
        scanner.startScan(100, 21); // this is the most smooth but crashes eventually
        led1 = 0;

        // CONNECTED STATE
        while (HIDinput.isConnected()) {
            led4 = 0;
            Thread::wait(300);
            led4 = 1;
            Thread::wait(300);
        }
        led2 = 0;

        led4 = 1;
        combinedTask.stopUpdateTask();
        scanner.stopScan();
    }
}

void blink() {
    led2 = 1;
    led1 = 0;
    for (;;) {
        led1 = !led1;
        led2 = !led2;
        printf("Hi!\r\n");
        Thread::wait(520);
    }
}

int main() {
    /*
     * The current setup with main.cpp is to have single calls to
     * test functions so we can each have test code without having
     * to comment out/have multiple versions.
     * Just change your local one to call the test loop you need.
     */
    launch();
}

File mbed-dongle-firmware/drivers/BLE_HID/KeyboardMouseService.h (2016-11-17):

/* mbed Microcontroller Library
 * Copyright (c) 2015 ARM Limited
 *
 * Licensed under the Apache License, Version 2.0 (the "License");
 * you may not use this file except in compliance with the License.
 * You may obtain a copy of the License at
 *
 *     http://www.apache.org/licenses/LICENSE-2.0
 *
 * Unless required by applicable law or agreed to in writing, software
 * distributed under the License is distributed on an "AS IS" BASIS,
 * WITHOUT WARRANTIES OR CONDITIONS OF ANY KIND, either express or implied.
 * See the License for the specific language governing permissions and
 * limitations under the License.
 */

#ifndef KEYBOARD_MOUSE_SVC_H
#define KEYBOARD_MOUSE_SVC_H

#include "mbed.h"
#include "ble/BLE.h"
#include "HIDServiceBase.h"
#include "Keyboard_types.h"


/******************** DEFINITIONS ********************/

#define REPORT_ID_KEYBOARD 1
#define REPORT_ID_MOUSE 2
#define REPORT_ID_VOLUME 3

#define MOUSE_REPORT_LENGTH 5
#define KBD_REPORT_LENGTH 9
#define KBD_USAGE_LENGTH 6
#define MAX_REPORT_LENGTH 9
#define REPORT_TICKER_PERIOD 100


/******************** ENUMERATIONS ********************/

/* Mouse button state */
enum ButtonState { UP, DOWN };

/* Mouse button select */
enum MouseButton {
    LEFT   = 0x1,
    RIGHT  = 0x2,
    MIDDLE = 0x4
};

/* Mouse direction select */
enum MouseDirection { X, Y, SCROLL };


/******************** STRUCTURES AND CLASSES ********************/

/* Represent the report descriptor as an array of bytes and
 * in a human-readable format for easy modification */
typedef union {

    /* Keyboard */
    typedef struct {
        uint8_t report_id;      // byte 0
        uint8_t modifier;       // byte 1
        uint8_t reserved;       // byte 2
        uint8_t usage[KBD_USAGE_LENGTH];       // bytes 3-8
    } keyboard_t;

    /* MOUSE */
    typedef struct {
        uint8_t report_id;      // byte 0
        uint8_t buttons;        // byte 1
        uint8_t x_speed;        // byte 2
        uint8_t y_speed;        // byte 3
        uint8_t scroll_speed;   // byte 4
        uint8_t unused[4];      // bytes 5-8
    }  mouse_t;
    
    /* Report sent over BLE */
    uint8_t report[MAX_REPORT_LENGTH];
    mouse_t mouse;
    keyboard_t keyboard;
    
} hid_report_t;


/* Class for using both mouse and keyboard services together */
class KeyboardMouseService : public HIDServiceBase {

public:

    /* Constructor */
    KeyboardMouseService(BLE &_ble);
    
    /******************** SENDING REPORTS ********************/
    ble_error_t sendKeyboardReport();
    ble_error_t sendMouseReport();        
    
    /******************** KEYBOARD INTERFACE ********************/

    /* Set the values for which keys are pressed */
    void keyPress(uint8_t * keys, int len, uint8_t modifier);
    
    /* Set the key values without changing the modifier */
    void keyPress(uint8_t * keys, int len);
    
    /* Send an empty report, indicating all keys were released */
    void keyRelease(void);
    
    /******************** MOUSE INTERFACE ********************/

    /* Set a button to be pressed or released */
    void setMouseButton(MouseButton button, ButtonState state);
    
    /* Set the speed of the mouse cursor in any or all directions */
    void setMouseSpeedX(int8_t speed);
    void setMouseSpeedY(int8_t speed);
    void setMouseScroll(int8_t speed);
    void setMouseSpeedAll(int8_t x, int8_t y, int8_t scroll);


    /******************** OTHER FUNCTIONS ********************/

    /* Callback for periodic sending of packets */
    virtual void sendCallback(void) { return; }

    /* Setter for connected bool */
    virtual void setConnected(bool connected) {
        this->connected = connected;
    }
    
    
private:

    /******************** PRIVATE VARIABLES ********************/

    /* HID report which gets sent over BLE */
    hid_report_t hid_report;

    /* Mouse variables */
    uint8_t mouse_buttons;
    int8_t mouse_x;
    int8_t mouse_y;
    int8_t mouse_scroll;    
    
    /* Keyboard variables */
    uint8_t usage[KBD_USAGE_LENGTH];
    uint8_t modifier;
    
};


#endif /* KEYBOARD_MOUSE_SVC_H */

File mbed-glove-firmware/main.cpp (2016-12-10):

/*
 * Filename:  main.cpp
 * Project:   EECS 473 - Team GLOVE
 * Date:      Fall 2016
 * Authors:
 *     Nick Bertoldi
 *     Ben Heckathorn
 *     Ryan O’Keefe
 *     Adrian Padin
 *     Tim Schumacher
 *
 * Purpose:
 *  Defines the function of the glove firmware and
 *  its idle lights pattern
 *
 * Copyright (c) 2016 by Nick Bertoldi, Ben Heckathorn, Ryan O'Keefe,
 *                       Adrian Padin, Timothy Schumacher
 *
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
 * THE SOFTWARE IS PROVIDED "AS IS", WITHOUT WARRANTY OF ANY KIND, EXPRESS
 * OR IMPLIED, INCLUDING BUT NOT LIMITED TO THE WARRANTIES OF MERCHANTABILITY,
 * FITNESS FOR A PARTICULAR PURPOSE AND NONINFRINGEMENT. IN NO EVENT SHALL
 * THE AUTHORS OR COPYRIGHT HOLDERS BE LIABLE FOR ANY CLAIM, DAMAGES OR OTHER
 * LIABILITY, WHETHER IN AN ACTION OF CONTRACT, TORT OR OTHERWISE, ARISING FROM,
 * OUT OF OR IN CONNECTION WITH THE SOFTWARE OR THE USE OR OTHER DEALINGS
 * IN THE SOFTWARE.
 */

#include <inttypes.h>
#include <utility>

#include "mbed.h"

#include "drivers/collector.h"
#include "drivers/ble_advert.h"
#include "drivers/dot_star_leds.h"

extern void blink(void);
extern void boot_delay(uint8_t);
extern void sensors_to_lights(void);
extern void ble_scan_test(void);
extern void uart_test(void);
extern void advert_test(void);
extern void touch_to_lights(void);
extern void imu_to_lights(void);

typedef pair<DotStarColor, DotStarColor> color_pair_t;
#if defined RIGHT_GLOVE
const uint8_t num_led_patterns_c = 2;
const color_pair_t led_patterns_c[num_led_patterns_c] = {
    color_pair_t(Blue, Maize),
    color_pair_t(Maize, Blue),
};
const uint8_t portal_intensity_c = 12;
const DotStarColor portal_color_c = Blue;
#elif defined LEFT_GLOVE
const uint8_t num_led_patterns_c = 3;
const color_pair_t led_patterns_c[num_led_patterns_c] = {
    color_pair_t(Blue, Cyan),
    color_pair_t(Red, Magenta),
    color_pair_t(Green, Yellow),
};
const uint8_t portal_intensity_c = 11;
const DotStarColor portal_color_c = Orange;
#else
#error "Must define either LEFT_GLOVE or RIGHT_GLOVE"
#endif

/*
 * Use this to signal or very the lights based on
 * the glove data or return true to let the set
 * pattern continue.
 */
bool check_signal_conditions(const glove_sensors_raw_t& glove_data, DotStarLEDs& leds) {
    /*
     * Indicate IMU flatlining
     */
    float ubound = 0.001;
    float lbound = ubound - (2*ubound);
    if ((lbound < glove_data.imu.orient_pitch && glove_data.imu.orient_pitch < ubound)
         && (lbound < glove_data.imu.orient_roll && glove_data.imu.orient_roll < ubound)) {

        leds.set_color_all(Pink, 10);
        return false;
    }

    /*
     * Indicate the first flex sensor is pulled
     */
    if (glove_data.flex_sensors[0] < 500) {
        leds.set_color_all(portal_color_c, portal_intensity_c);
        return false;
    }

    /*
     * Indicate a touch has occured
     */
    if (glove_data.touch_sensor.a || glove_data.touch_sensor.b || glove_data.touch_sensor.c || glove_data.touch_sensor.d) {
        leds.set_color_all(Magenta, 3);
        return false;
    }

    return true;
}

void launch() {
    DigitalOut l1(LED1);
    DigitalOut l2(LED2);
    DigitalOut l3(LED3);
    DigitalOut l4(LED4);
    l1 = 1; l2 = 1; l3 = 1; l4 = 1;

    DotStarLEDs ds_leds(2);
    ds_leds.set_color_all(White);

    // used by glove sensors compressGloveData
    crcInit();

    I2C i2c(I2C_SDA0, I2C_SCL0); // Initialize i2c bus for imu and touch_sensor
    IMU_BNO055 imu(i2c);
    TouchSensor touch_sensor(i2c, TOUCH_INTERRUPT);
    FlexSensors flex_sensors;

    // This encapsulates the BLE stack
    AdvertBLE adble;

    Collector collector(flex_sensors, imu, touch_sensor, adble);
    collector.startUpdateTask(20);
    const glove_sensors_raw_t& glove_data = collector.getGloveSensorData();

    //Blink blk(adble); blk.startUpdateTask();
    l1 = 0;

    //glove_sensors_raw_t glove_data;

    for (;;) {
        l2 = !l2;
        adble.waitForEvent();
        Thread::wait(50);
    }
    l1 = 0;
    DigitalOut d1(p20);
    /* The following main loop sets the light pattern on the
     * gloves after all the sensors have been initialized,
     * the BLE advertising set up, and the collector is running
     */
    for (;;) {
        //printf("f: %d, t: 0x%x\r\n", collector.flex_data[0], collector.touch_data->pack());
        //printf("comp: %d, fp: %f\r\n", compress_double(110.565), extract_double(11056));

        for (uint8_t i = 0; i < num_led_patterns_c; ++i) {
            l1 = !l1;
            for (int j=0; j < 50; ++j) {
                if (check_signal_conditions(glove_data, ds_leds)) {
                    ds_leds.set_color(0, led_patterns_c[i].first);
                    ds_leds.set_color(1, led_patterns_c[i].second);
                }
                Thread::wait(10);
            }
        }
    }
}

int main() {

    /*
     * The current setup with main.cpp is to have single calls to
     * test functions so we can each have test code without having
     * to comment out/have multiple versions.
     * Just change your local one to call the test loop you need.
     */
    launch();
}

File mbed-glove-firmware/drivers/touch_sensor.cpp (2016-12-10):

/*
 * Filename:  touch_sensor.cpp
 * Project:   EECS 473 - Team GLOVE
 * Date:      Fall 2016
 * Authors:
 *     Nick Bertoldi
 *     Ben Heckathorn
 *     Ryan O’Keefe
 *     Adrian Padin
 *     Tim Schumacher
 *
 * Purpose:
 *   Top-level interface for working with capacitive sensor chip,
 *   which uses I2C and can communicate the values of up to 7 sensors
 *
 *   The AT42QT1070 in I2C comms mode can use a single interrupt line
 *   to indicate a change in state of the sensors.
 *
 * Copyright (c) 2016 by Nick Bertoldi, Ben Heckathorn, Ryan O'Keefe,
 *                       Adrian Padin, Timothy Schumacher
 *
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
 * THE SOFTWARE IS PROVIDED "AS IS", WITHOUT WARRANTY OF ANY KIND, EXPRESS
 * OR IMPLIED, INCLUDING BUT NOT LIMITED TO THE WARRANTIES OF MERCHANTABILITY,
 * FITNESS FOR A PARTICULAR PURPOSE AND NONINFRINGEMENT. IN NO EVENT SHALL
 * THE AUTHORS OR COPYRIGHT HOLDERS BE LIABLE FOR ANY CLAIM, DAMAGES OR OTHER
 * LIABILITY, WHETHER IN AN ACTION OF CONTRACT, TORT OR OTHERWISE, ARISING FROM,
 * OUT OF OR IN CONNECTION WITH THE SOFTWARE OR THE USE OR OTHER DEALINGS
 * IN THE SOFTWARE.
 */

#include "touch_sensor.h"

TouchSensor::TouchSensor(PinName sda, PinName scl, PinName intr) : qt(sda, scl) {
    initialize(intr);
}

TouchSensor::TouchSensor(I2C& i2c, PinName intr)
    : qt(i2c) {
    initialize(intr);
}

void TouchSensor::initialize(PinName intr) {
    needs_restart = false;
    writeStaticConfig();
    qt.getButtonsState();

    // Associate the update function with the interrupt CHANGE line
    if (intr != NC) {
        if (TOUCH_DIGITALIN_CHANGE) {
            change_line = new DigitalIn(intr);
        }
        else {
            change_event = new InterruptIn(intr);
            change_event->fall(this, &TouchSensor::changeEventHandler);
        }
    }
    keys.a = 0;
    keys.b = 0;
    keys.c = 0;
    keys.d = 0;
}

void TouchSensor::writeStaticConfig() {
    qt.setGuard(TOUCH_GUARD_KEY);
    qt.setLowPowerMode(TOUCH_LP_MODE);
    qt.setMaxOn(TOUCH_MAX_ON);

    for (uint8_t k = 0; k < 7; ++k) {
        qt.setThreshold(k, TOUCH_NTHRESHOLD);
        qt.setDetectionIntegrator(k, TOUCH_DI);
        qt.setAVE(k, TOUCH_AVE);
        qt.setAKSGroup(k, TOUCH_AKS[k]);
    }
}

void TouchSensor::writeKeys(key_states_t* key_states) {
    key_states->a = keys.a;
    key_states->b = keys.b;
    key_states->c = keys.c;
    key_states->d = keys.d;
}

void TouchSensor::update() {
    /*
     * Use the change line to avoid unnessescary
     * I2C I/O, but without being an interrupt
     */
    if (*change_line == 1) {
        return;
    }

    uint8_t buttons = qt.getButtonsState();

    // Check overflow flag
    if (buttons & 0x80) {
        // do something about it
        return;
    }

    // just get the keys we want
    keys.a = (buttons & 0x01); // key 0
    keys.b = (buttons & 0x02) >> 1; // key 1
    keys.c = (buttons & 0x04) >> 2; // key 2
    keys.d = (buttons & 0x08) >> 3; // key 3
    //keys.e = buttons & 0x10; // key 4
    //keys.f = buttons & 0x20; // key 5
    //keys.g = buttons & 0x40; // key 6
}

void TouchSensor::updateAndWrite(key_states_t* key_states) {
    update();
    writeKeys(key_states);
}

void TouchSensor::reset() {
    qt.reset();
    writeStaticConfig();
    qt.getButtonsState();
}

void TouchSensor::changeEventHandler() {
    do_update.release();
}

void TouchSensor::updateTask() {
    for (;;) {
        do_update.wait(osWaitForever);
        update();
    }
}
static DigitalOut l3(LED3);
void TouchSensor::singleUpdate() {
    //if (needs_restart) {
        //reset(); // This broke everything :( cuz it takes too long (disable irq??)
        //qt.reset();
        //qt.getButtonsState();
    //}

    needs_restart = true;
    l3 = 0;
    update();
    l3 = 1;
    needs_restart = false;

    update_thread->terminate();
}

void TouchSensor::spawnUpdateThread() {
    update_thread = new Thread;
    update_thread->start(this, &TouchSensor::singleUpdate);
    Thread::yield();
}

void TouchSensor::terminateUpdateThreadIfBlocking() {
    if (needs_restart) {
        update_thread->terminate();
        // Leave reset in the update funtion cuz don't block here
    }
    delete update_thread;
    update_thread = NULL;
}

void TouchSensor::print(Serial& pc, key_states_t& keys_) {
    pc.printf("Keys: %hu %hu %hu %hu\r\n",
            keys_.a, keys_.b, keys_.c, keys_.d);
}

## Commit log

2016-10-05 Flex sensor interface
2016-10-05 Added the class for the glove sensor data structure
2016-10-06 Working on IMU lib
2016-10-06 Added orientation/acceleration & update() for IMU
2016-10-06 GPIO comments and init for touch sensor
2016-10-13 Added Eagle Files
    [glove.brd, glove.sch]
2016-10-13 Added the "Blinkey" main for our board
2016-10-13 Working on a script to flash the board fast
2016-10-13 Better mounting logic; more cli opts
2016-10-13 Flex sensor roughed in with the lower-level api
2016-10-13 Implemented better flex sensor
    [main.cpp]
2016-10-18 Added Lab 11 libraries / Started charging circuit
    [glove.brd, glove.sch]
2016-10-20 Started imu test in main
2016-10-20 Added test to main for imu
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2016-10-20 Working on porting lib to our board
2016-10-20 Updated touch sensor for I2C
2016-10-21 First interfacing is working on the IMU
2016-10-21 Starting on the top-level library to handle the details of the imu
2016-10-21 Finished sketching out the IMU interface
2016-10-21 Removed extraneous eagle files
    [glove.brd, glove.sch]
2016-10-21 Working on implementation for imu lib
2016-10-21 Added imu.cpp beginning implementation
2016-10-21 Better flex test in main
    [main.cpp]
2016-10-21 Updates the flex sensors
2016-10-21 Print the deflection, dummy
2016-10-24 Finished routing nearly completed board
    Still lots of modifications to make, but it's a start.
    [glove.brd, glove.sch]
2016-10-24 Finished routing nearly complete board
    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
    [glove.brd, glove.sch]
2016-10-24 Move our src into drivers/
2016-10-24 Added an independent library for the capacitive sensors
2016-10-24 Touch sensors top-level interface
    Uses the AT42QT1070 lib
2016-10-24 Better use of PinNames in our drivers
2016-10-25 Starting touch sensor cpp initialization
2016-10-25 Added traces to board for I2C
    [glove.brd, glove.sch]
2016-10-26 Fixed repo error
    [glove.brd, glove.sch]
2016-10-26 remove glove_eagle
    [glove.brd, glove.sch]
2016-10-26 Small compiler/syntax fixes for touch realtime
    [touch_sensor.cpp]
2016-10-26 Added touch sensor integration test to main
2016-10-26 Worked on the BOM
    [glove.brd, glove.sch]
2016-10-26 Started work on BOM
    [glove.brd, glove.sch]
2016-10-26 Working on the thread spawning...
2016-10-26 Working Thread start call now!
2016-10-26 "CHANGE" line bug fix
    We depend on change line being reset, however that would not happen if BOTH status reg were not read. On button release event, REG_KEYSTATUS was not being read because no keys were pressed (only released). Issue corrected.
2016-10-26 Fixing things yaayyy
    Added button state poll in Touch constructor to allow change line to float high
    [touch_sensor.cpp]
2016-10-27 Added pin seletions by target
2016-10-27 Add board v dev kit copmile option to fla.sh
2016-10-27 Removed old draft versions of part drivers
2016-10-28 It's a board
    We got this
    [glove.brd, glove.sch]
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2016-10-28 Updated glove sensors definitions
2016-10-28 Updated the flex sensors
2016-10-28 Periodic timer stuff running for FlexSensors
2016-10-28 lol haf done boardl
    [glove.brd, glove.sch]
2016-10-28 Library for diode and transistor
2016-10-28 54 wires left! (woo?)
    [glove.brd, glove.sch]
2016-10-28 Unified the interfaces between flex and imu
2016-10-28 New task-based implementation for imu
2016-10-28 Adds imu to main
2016-10-31 Did a few more easy wires. 44 left!
    [glove.brd, glove.sch]
2016-10-31 Completely routed!
    Some final layout tweaks needed, but everything is connected and it looks like it works
    [glove.brd, glove.sch]
2016-10-31 Adds timer definition for Collector
2016-11-01 Need to finish silkscreen
    [glove.brd, glove.sch]
2016-11-02 Silkscreen/SPI LEDs
    Cleaned up silk screen layer.
    Added SPI connectors to schematic - still need to route.
    [glove.brd, glove.sch]
2016-11-02 Added SPI LEDs to board
    Need to fix clearance
    [glove.brd]
2016-11-03 Adjusted Silkscreen
    Named and adjusted pads and added slikscreen text
    [glove.brd, glove.sch]
2016-11-03 Initialize with i2c ref instead of pins
2016-11-03 Moved some parts slightly and ADDED PWR LED
    Possible issues with bus routing
    [glove.brd, glove.sch]
2016-11-03 Got the touch sensor bug worked out
    [main.cpp, touch_sensor.cpp]
2016-11-03 Renamed Parts/Updated BOM
    [glove.brd, glove.sch]
2016-11-04 The board is done...hopefully
    [glove.brd, glove.sch]
2016-11-04 Flex sensor printSingle fix, main updates
    [main.cpp]
2016-11-04 turns out they're not quite done...damn
    [glove.brd, glove.sch]
2016-11-05 Most final board issues fixed - one or two to go
    [glove.brd, glove.sch]
2016-11-06 Using the right mounting point
2016-11-06 Likely Ready to Order
    [glove.brd, glove.sch]
2016-11-06 Optional compile for two differing prototype gloves
2016-11-06 DONT lock around printf with rtos tasks...
2016-11-07 Added Gerber Files
    [glove.brd, glove.sch]
2016-11-08 First analog button class
2016-11-08 Finished fleshing out the analog button
2016-11-08 beginning to build on top of analog button
2016-11-08 Modified some analog_button functionality
    Realised that since any one sensor only represents one portion of a mouse, not whole mouse, the old
    design of mouseData did not make much sense. Redesign to new scheme that mirrors keyboardData
2016-11-08 A bunch of demo code for the glove prototype
2016-11-08 Adds option to set all leds in strand
2016-11-09 Tweaks to the imu->lights code, imu mount point
2016-11-09 Added simple debug out pin
2016-11-11 Translator: switched vector implementation to array
2016-11-11 New LED status thing with all 3 sensors
2016-11-14 Updates for new HID api. Potential fixes for main. Working spacebar demo for flexsensor1 in main
    [main.cpp]
2016-11-14 added wasd function to keyboard mous demo. It works with touch sensors!
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2016-11-15 Removes mutex, rtos timer from flex sensors
2016-11-15 Removes mutex, debug out pin from touch sensors
2016-11-15 Moved all the sensor-only tests into own file
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2016-11-17 Updates for updated touch sensor implementation within main and translator
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2016-11-17 flex sensor for analog_button is completed, not tested
2016-11-17 imu is on its way. still need to do analog to analog conversion for it
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2016-11-18 Demo with flex sensor mapped to 'a'
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2016-11-21 flex sensor works as keyboard AND MOUSE bitches!
    [main.cpp]
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2016-11-21 changes to hopefully have imu to mouse axis working
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2016-11-30 Still breaking into the unknown error state
    [main.cpp]
2016-12-01 Fixed dependencies to get code to compile
    [at42qt1070.h, touch_sensor.cpp]
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2016-12-01 fixed references issues in glove-firmware
    [main.cpp]
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2016-12-01 Fixes to main to compile code
    [main.cpp]
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2016-12-02 Still having major stability issues
    [main.cpp]
2016-12-02 Fixes to scanning and serial receiving
    [main.cpp]
2016-12-03 Trying to fix things...:
    [main.cpp]
2016-12-03 Fix keyboard but analog button broken
    [main.cpp]
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2016-12-05 Full translator logic for ALL flex and touch sensors, IMU on the way
    [main.cpp]
2016-12-06 fully functional translator, imu analog values still need to be tested
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2016-12-06 Adds working, tested version of glove data (de)compress
2016-12-07 Trying to fix ble
    [main.cpp]
2016-12-07 imu logic needs fixing, config app is functional
    [main.cpp]
2016-12-07 Flex to 'a' testing
    [main.cpp]
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2016-12-07 Using threads for the touch in the unit test
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2016-12-07 readded the print stuff in main (why were they even commented out?)
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2016-12-07 Added caching to the leds to remove quiver
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2016-12-08 Swap pitch/roll; disable serialInt
    [main.cpp]
2016-12-08 Analog button and translator refactor; new out of memory
2016-12-08 "Op new out of mem" error is gone
    [main.cpp]
2016-12-08 My Orange is orange you glad im a door hinge?
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

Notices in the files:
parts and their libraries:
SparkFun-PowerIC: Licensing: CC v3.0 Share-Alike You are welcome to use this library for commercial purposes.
